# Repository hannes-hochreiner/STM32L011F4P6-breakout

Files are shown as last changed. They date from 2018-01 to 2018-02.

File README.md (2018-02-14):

# STM32L011F4P6-breakout
Simple breakout board for the STM32L011F4P6

## Flash test
I tested flashing the breakout using a raspberry pi and OpenOCD.
For installing OpenOCD, I followed the tutorial on [adafruit.com](https://learn.adafruit.com/programming-microcontrollers-using-openocd-on-raspberry-pi/compiling-openocd).
I used the following configuration:
```
source [find interface/raspberrypi-native.cfg]
transport select swd
source [find target/stm32l0.cfg]
bcm2835gpio_swd_nums 25 24
bcm2835gpio_trst_num 7
bcm2835gpio_srst_num 18
reset_config srst_nogate

adapter_nsrst_delay 100
adapter_nsrst_assert_width 100

init
targets
reset halt
```
I started OpenOCD with the configuration...
```
sudo openocd -f stm32.cfg
```
...and connected through telnet to it...
```
telnet localhost 4444
```
I then flashed a small test program:
```
program stmTest.hex verify reset
```

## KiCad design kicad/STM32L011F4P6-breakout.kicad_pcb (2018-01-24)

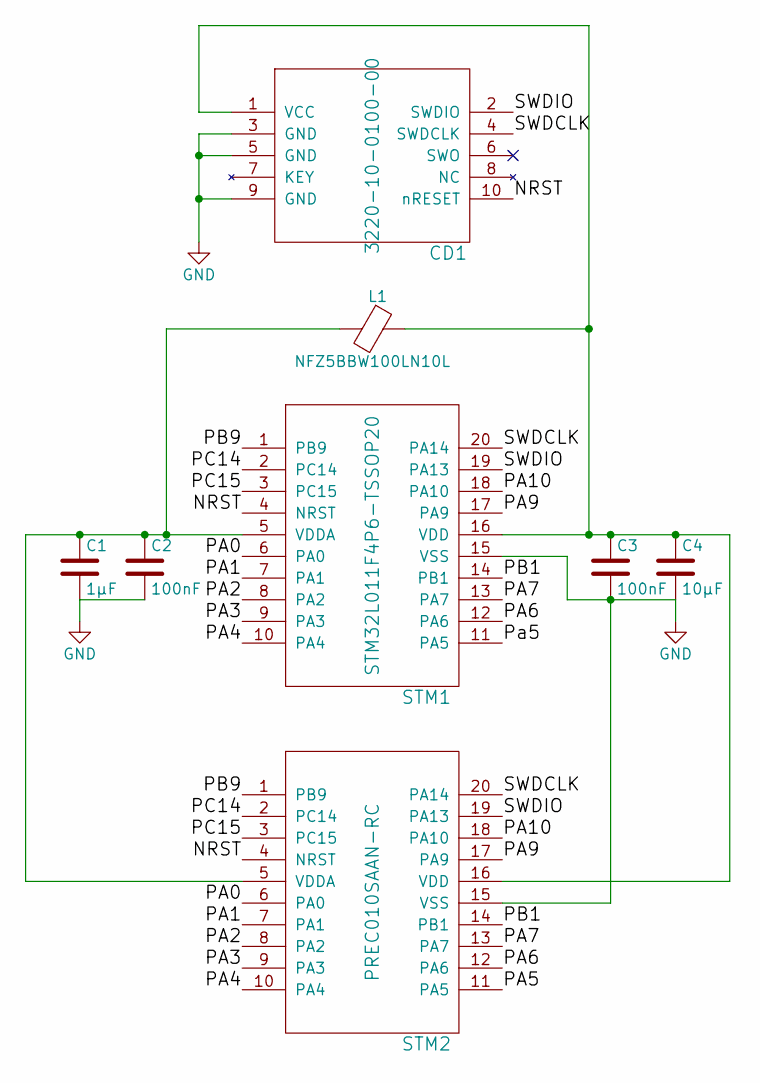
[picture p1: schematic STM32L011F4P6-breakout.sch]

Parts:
C1: 1µF; C_0603_HandSoldering
C2, C3: 100nF; C_0603_HandSoldering
C4: 10µF; C_0603_HandSoldering
CD1: 3220-10-0100-00; CORTEX-DEBUG
L1: NFZ5BBW100LN10L; C_2220_HandSoldering
STM1: STM32L011F4P6-TSSOP20; TSSOP-20_4.4x6.5mm_Pitch0.65mm
STM2: PREC010SAAN-RC; STM32CONN

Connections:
/NRST: CD1.10 (nRESET), STM1.4 (NRST), STM2.4 (NRST)
/PA0: STM1.6 (PA0), STM2.6 (PA0)
/PA1: STM1.7 (PA1), STM2.7 (PA1)
/PA2: STM1.8 (PA2), STM2.8 (PA2)
/PA3: STM1.9 (PA3), STM2.9 (PA3)
/PA4: STM1.10 (PA4), STM2.10 (PA4)
/PA5: STM1.11 (PA5), STM2.11 (PA5)
/PA6: STM1.12 (PA6), STM2.12 (PA6)
/PA7: STM1.13 (PA7), STM2.13 (PA7)
/PA9: STM1.17 (PA9), STM2.17 (PA9)
/PA10: STM1.18 (PA10), STM2.18 (PA10)
/PB1: STM1.14 (PB1), STM2.14 (PB1)
/PB9: STM1.1 (PB9), STM2.1 (PB9)
/PC14: STM1.2 (PC14), STM2.2 (PC14)
/PC15: STM1.3 (PC15), STM2.3 (PC15)
/SWDCLK: CD1.4 (SWDCLK), STM1.20 (PA14), STM2.20 (PA14)
/SWDIO: CD1.2 (SWDIO), STM1.19 (PA13), STM2.19 (PA13)
GND: C1.2, C2.2, C3.2, C4.2, CD1.3 (GND), CD1.5 (GND), CD1.9 (GND), STM1.15 (VSS), STM2.15 (VSS)
unnamed: C1.1, C2.1, L1.2, STM1.5 (VDDA), STM2.5 (VDDA)
unnamed: C3.1, C4.1, CD1.1 (VCC), L1.1, STM1.16 (VDD), STM2.16 (VDD)

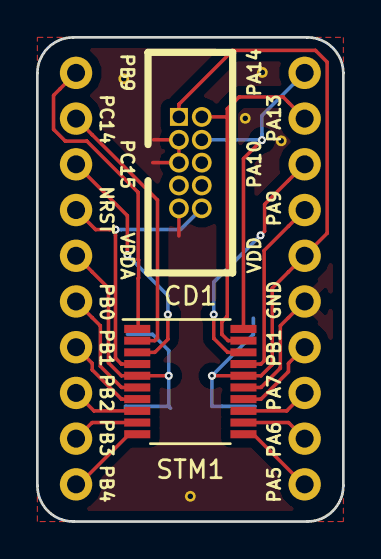
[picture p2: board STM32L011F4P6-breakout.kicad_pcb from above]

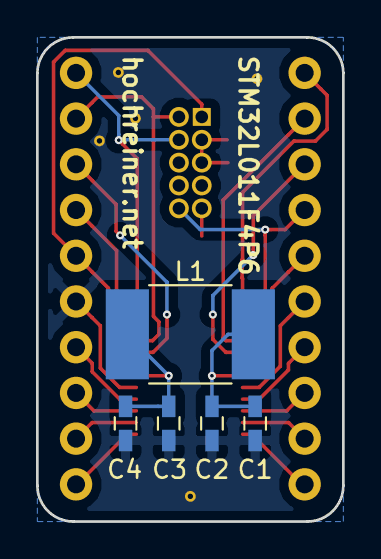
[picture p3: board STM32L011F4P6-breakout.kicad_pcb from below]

Board: 2 copper layers, 17.0 x 26.9 mm, 8 parts (5 on the bottom side), 20 nets.

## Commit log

2017-09-27 first snapshot
    [STM32L011F4P6-breakout.kicad_pcb, STM32L011F4P6-breakout.sch]
2017-12-02 moved STM down and rotated debug connector
    [STM32L011F4P6-breakout.kicad_pcb]
2018-01-22 aligned footprints and added pin labels
    [STM32L011F4P6-breakout.kicad_pcb, STM32L011F4P6-breakout.sch]
2018-01-22 increased board margin by moving a trace closer to the pins
    [STM32L011F4P6-breakout.kicad_pcb]
2018-01-23 re-aligned pin labels
    [STM32L011F4P6-breakout.kicad_pcb]
2018-01-24 changed ferrite bead
    [STM32L011F4P6-breakout.kicad_pcb, STM32L011F4P6-breakout.sch]
